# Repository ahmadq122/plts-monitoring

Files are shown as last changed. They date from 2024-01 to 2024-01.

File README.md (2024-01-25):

# PLTS Monitoring
A monitoring device for solar power plants
This device can read data from the solar panel system, measure current and voltage, and store data using microSD card media. 
In addition, the device has a user interface to display the measured data using an LCD 20x04.

## The block diagram of the solar power system monitoring system, including sensors, microcontroller, and user interface is as follows:
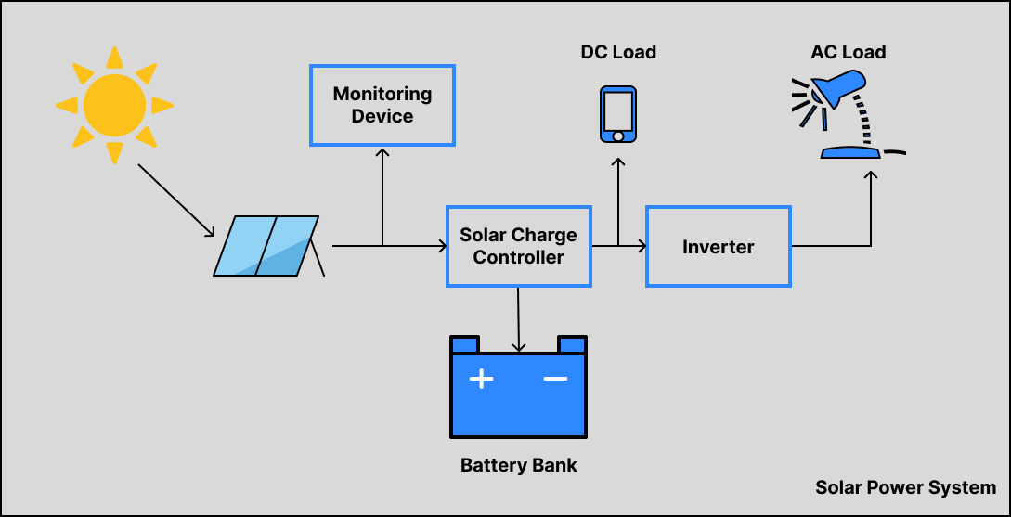
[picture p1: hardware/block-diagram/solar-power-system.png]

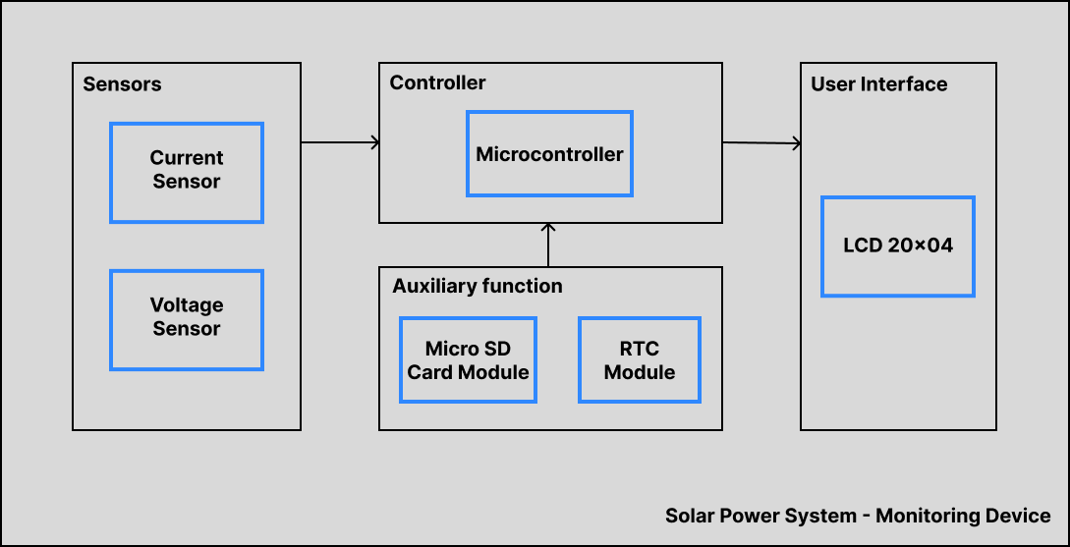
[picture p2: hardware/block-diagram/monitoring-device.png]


## Description of how the device works in general:
This tool will measure the voltage value generated by a solar panel and the DC electric current that is being flowed.
The measurement results will then be recorded in a certain time interval into a file document in a Micro SD card.

## The type of sensor that will be used to measure the current and voltage of the solar panel:
Current Sensor: ACS712
Voltage Sensor: ACPL-C87B

## Reasons for selecting the sensor:
ACS712
- Output voltage proportional to AC or DC currents
- Low-noise analog signal path
- Commonly used sensor and small output error 1.5% at Ambient temp 25C
- 
ACPL-C87B
- Isolated DC-bus voltage sensing
- High accuracy
- 0.1% non-linearity max
- 

## Schematic and PCB design using EDA application (Kicad):
- Please check kicad folder

## Create source code for the microcontroller (AVR ATmega 328p)
- Please check firmware folder

## Simulate the device design using the Proteus application:
- Please check proteus folder

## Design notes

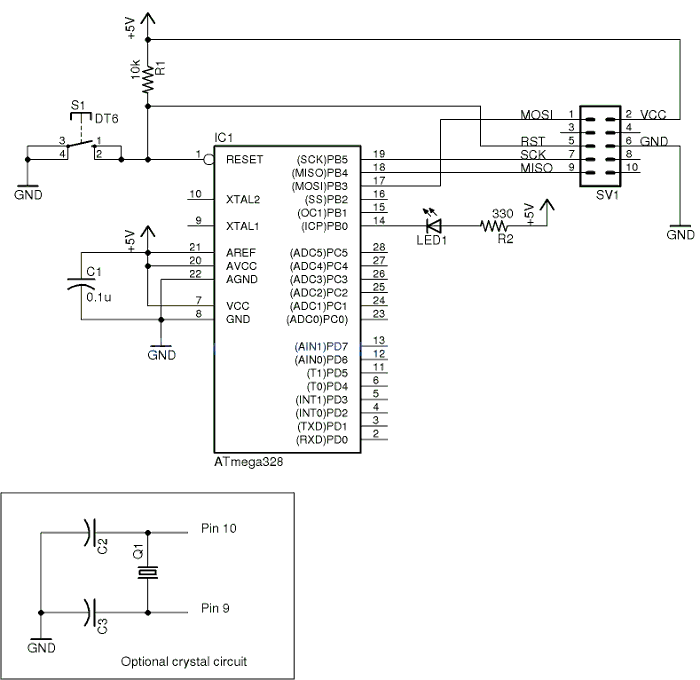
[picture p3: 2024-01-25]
hardware/controller/Minimum system.gif

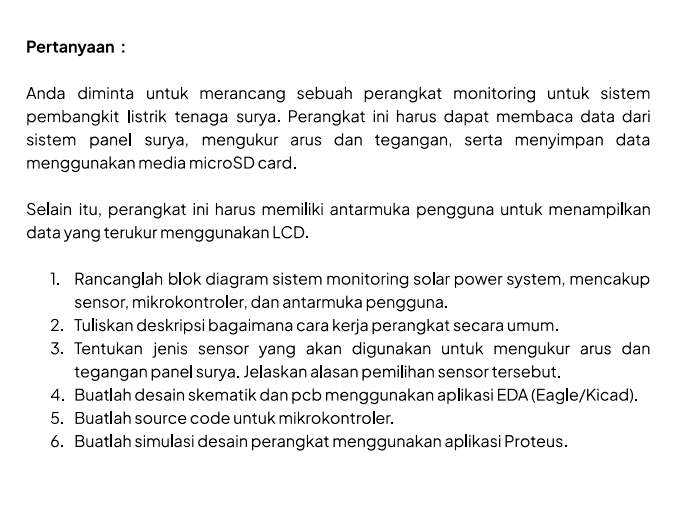
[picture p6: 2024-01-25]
task/task.png

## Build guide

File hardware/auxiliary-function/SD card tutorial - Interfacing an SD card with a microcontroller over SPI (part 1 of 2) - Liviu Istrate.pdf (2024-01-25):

SD card tutorial - Interfacing an SD card with a microcontroller over SP... https://www.programming-electronics-diy.xyz/2022/07/sd-card-tutorial-...

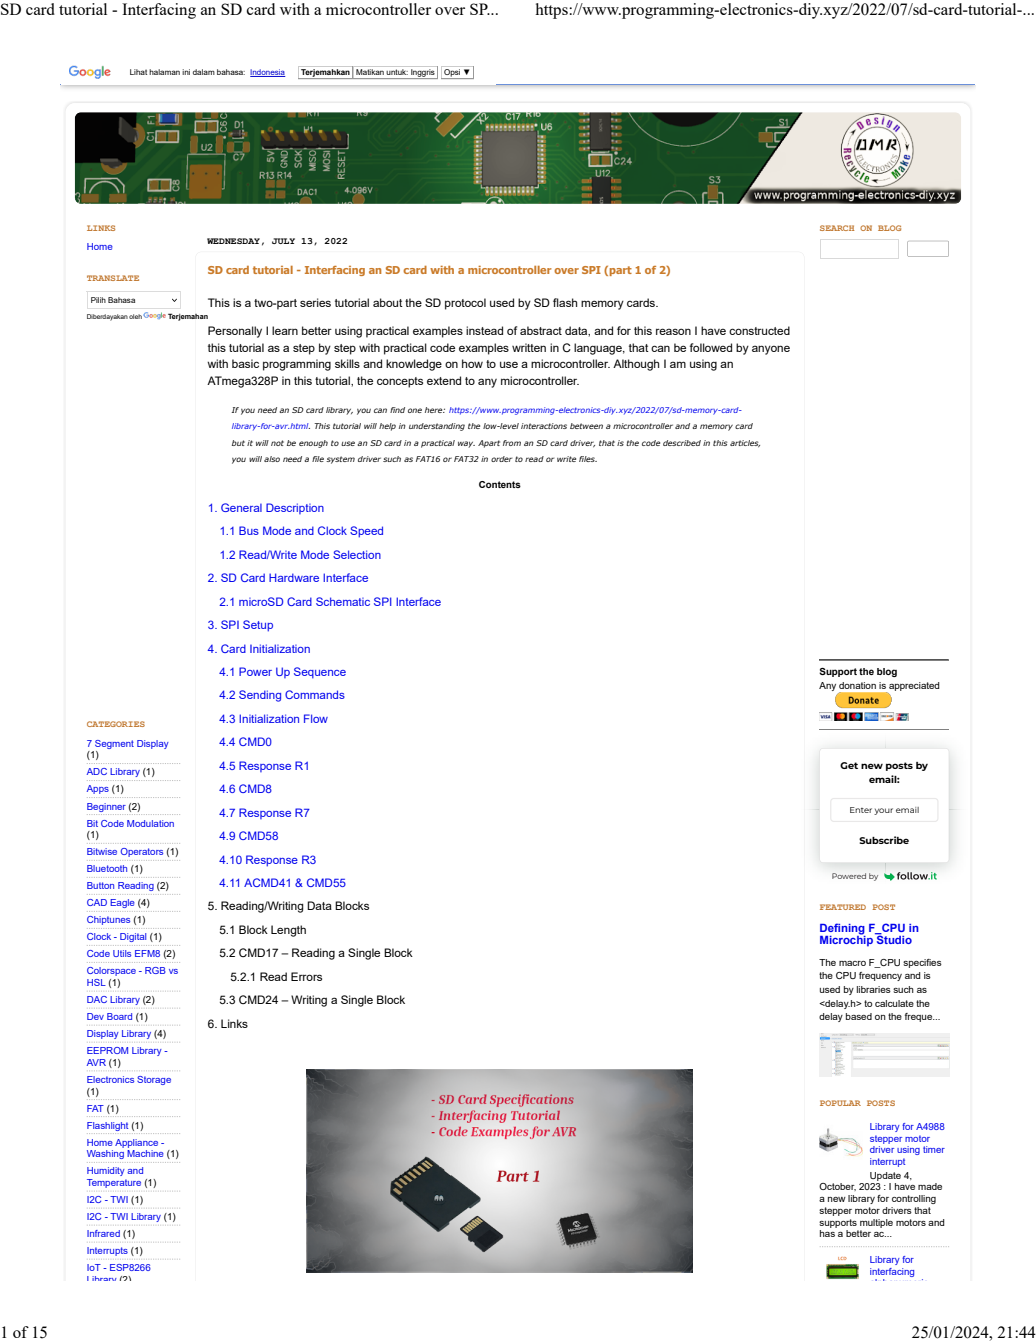
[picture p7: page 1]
WEDNESDAY, JULY 13, 2022; Contents; Home; LINKS; Pilih Bahasa; Diberdayakan oleh; Terjemahan; TRANSLATE; 7 Segment Display (1); ADC Library (1); Apps (1); Beginner (2); Bit Code Modulation (1); Bitwise Operators (1); Bluetooth (1); Button Reading (2); CAD Eagle (4); Chiptunes (1); Clock - Digital (1); Code Utils EFM8 (2); Colorspace - RGB vs HSL (1); DAC Library (2); Dev Board (1); Display Library (4); EEPROM Library - AVR (1); Electronics Storage (1); FAT (1); Flashlight (1)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

SEARCH ON BLOG

SD card tutorial - Interfacing an SD card with a microcontroller over SPI (part 1 of 2)

This is a two-part series tutorial about the SD protocol used by SD flash memory cards.

Personally I learn better using practical examples instead of abstract data, and for this reason I have constructed
this tutorial as a step by step with practical code examples written in C language, that can be followed by anyone
with basic programming skills and knowledge on how to use a microcontroller. Although I am using an
ATmega328P in this tutorial, the concepts extend to any microcontroller.

If you need an SD card library, you can find one here: https://www.programming-electronics-diy.xyz/2022/07/sd-memory-card-
library-for-avr.html. (https://www.programming-electronics-diy.xyz/2022/07/sd-memory-card-library-for-avr.html) This tutorial will help in understanding the low-level interactions between a microcontroller and a memory card
but it will not be enough to use an SD card in a practical way. Apart from an SD card driver, that is the code described in this articles,
you will also need a file system driver such as FAT16 or FAT32 in order to read or write files.

1. General Description (https://www.programming-electronics-diy.xyz/2022/07/sd-card-tutorial-interfacing-sd-card.html)
1.1 Bus Mode and Clock Speed (https://www.programming-electronics-diy.xyz/2022/07/sd-card-tutorial-interfacing-sd-card.html)
1.2 Read/Write Mode Selection (https://www.programming-electronics-diy.xyz/2022/07/sd-card-tutorial-interfacing-sd-card.html)
2. SD Card Hardware Interface (https://www.programming-electronics-diy.xyz/2022/07/sd-card-tutorial-interfacing-sd-card.html)
2.1 microSD Card Schematic SPI Interface (https://www.programming-electronics-diy.xyz/2022/07/sd-card-tutorial-interfacing-sd-card.html)
3. SPI Setup (https://www.programming-electronics-diy.xyz/2022/07/sd-card-tutorial-interfacing-sd-card.html)
4. Card Initialization (https://www.programming-electronics-diy.xyz/2022/07/sd-card-tutorial-interfacing-sd-card.html)
4.1 Power Up Sequence (https://www.programming-electronics-diy.xyz/2022/07/sd-card-tutorial-interfacing-sd-card.html)
4.2 Sending Commands (https://www.programming-electronics-diy.xyz/2022/07/sd-card-tutorial-interfacing-sd-card.html)
4.3 Initialization Flow (https://www.programming-electronics-diy.xyz/2022/07/sd-card-tutorial-interfacing-sd-card.html)
4.4 CMD0 (https://www.programming-electronics-diy.xyz/2022/07/sd-card-tutorial-interfacing-sd-card.html)
4.5 Response R1 (https://www.programming-electronics-diy.xyz/2022/07/sd-card-tutorial-interfacing-sd-card.html)
4.6 CMD8 (https://www.programming-electronics-diy.xyz/2022/07/sd-card-tutorial-interfacing-sd-card.html)
4.7 Response R7 (https://www.programming-electronics-diy.xyz/2022/07/sd-card-tutorial-interfacing-sd-card.html)
4.9 CMD58 (https://www.programming-electronics-diy.xyz/2022/07/sd-card-tutorial-interfacing-sd-card.html)
4.10 Response R3 (https://www.programming-electronics-diy.xyz/2022/07/sd-card-tutorial-interfacing-sd-card.html)
4.11 ACMD41 & CMD55 (https://www.programming-electronics-diy.xyz/2022/07/sd-card-tutorial-interfacing-sd-card.html)
5. Reading/Writing Data Blocks
5.1 Block Length
5.2 CMD17 – Reading a Single Block
5.2.1 Read Errors
5.3 CMD24 – Writing a Single Block
6. Links

Support the blog
Any donation is appreciated

Get new posts by
email:

Enter your email

The macro F_CPU specifies
the CPU frequency and is
used by libraries such as
<delay.h> to calculate the
delay based on the freque...

Library for A4988
stepper motor
driver using timer
interrupt (https://www.programming-electronics-diy.xyz/2017/10/library-for-a4988-stepper-motor-driver.html)
Update 4,

October, 2023 : I have made
a new library for controlling
stepper motor drivers that
supports multiple motors and
has a better ac...

Library (https://www.programming-electronics-diy.xyz/search/label/IoT%20-%20ESP8266%20Library) (2) | alphanumeric LCD modules with (https://www.programming-electronics-diy.xyz/2016/08/lcd-interfacing-library-4-and-8-bit-mode.html)

The Secure Digital (SD) Card was developed by the SD Association (SDA) (https://en.wikipedia.org/wiki/SD_Association) as an improvement over MMCs. The SD Card specifications were originally defined by MEI (Matsushita Electric Company), Toshiba Corporation and SanDisk Corporation. Currently, the specifications are controlled by the Secure Digital Association (SDA).

In addition to the mass storage specific flash memory chip, the SD Card includes an on-card intelligent controller which manages interface protocols, security algorithms for copyright protection, data storage and retrieval, as well as Error Correction Code (ECC) algorithms, defect handling and diagnostics, power management and clock control.

The data is transferred between the memory card and the host controller as data blocks in units of 512 bytes. The SD Card communication is based on an advanced nine-pin interface (Clock, Command, 4xData and 3xPower lines) designed to operate in a low voltage range. Both MMC/SD standards have their own proprietary protocols but they also support SPI which can be selected during card initialization. Since microcontrollers have SPI integrated hardware, this is the most used interface for memory cards.

SPI mode is a secondary mode of communication for SD cards – they power up in an "SD Bus protocol mode." To switch the card to SPI, the Chip Select line is driven low and CMD0 is sent.

The recommended file systems for memory cards are FAT12/16/32 or exFAT. Maximum volume sizes for each one are: 256MB, 4GB, 16TB* for FAT32 and 128PB for exFAT.

The MultiMediaCard and SD Card support multiple busses. Both cards support the 1-bit SPI bus that includes bus pins DATin, DATout, CLK, and CS.

The SD Card also supports a 4-bit and a 1-bit SD bi-directional bus mode. SD bus pins are CLK, CMD, and DATin 1-bit mode and CLK, CMD, and DAT[0:3] in 4-bit mode.

The MultiMediaCard also supports the 1-bit bi-directional MMC bus mode that has CLK, CMD, and DAT bus pins.

The CMD and DAT pins are bi-directional on the SD 1-bit, SD 4-bit, and MMC 1-bit.

The maximum burst rate achievable with the SD Card and MultiMediaCard depends on the clock speed and bus mode. The burst rate is the data transfer rate between the card’s buffer and host.

The write and read throughput rates of the SD Card and MultiMediaCard are slower than the burst rate because each card includes the busy time to write data from the card’s buffers to its internal Flash RAM, and busy time to read data from the internal Flash RAM to the card’s buffer. Since most designs use this write and read busy time to complete other processes, choosing a 1- or 4-bit bus mode can have a 4x speed effect on the time spent servicing the SD Card.

Another major MultiMediaCard and SD Card design consideration is the use of Singleblock or Multiblock command modes. Singleblock mode reads and writes data one block at a time; Multiblock mode reads and writes multiple blocks until a stop command is received.

Multiblock mode takes advantage of the multiple internal block buffers present in all MultiMediaCards or SD Cards. In Multiblock mode, when one block buffer gets full during write, the card gives the host access to the other empty block buffers to fill while programming the first block. The card does not enter a busy state until all block buffers are full.

In Singleblock mode, the card enters a busy state by forcing the DAT line low when the first block buffer is full and remains busy until the write process is complete. During the busy state, the host cannot send any additional data to the card because the card forces the DAT line low.

If speed is critical in a design, Multiblock mode is the faster and recommended mode. The more blocks that can be written in Multiblock mode the better the performance of the design. Therefore when planning the design, ensure that enough system RAM is designed in to support the multiblock capability. The performance gain will always outweigh the cost of the extra RAM. However, if speed is not critical – for example, a data-logger design that records only 512 bytes of data every minute – Singleblock mode is more than adequate.

### 1. GENERAL DESCRIPTION

### 1.1 BUS MODE AND CLOCK SPEED

Table 1: from "SanDisk Secure Digital Card v1.9"

### 1.2 READ/WRITE MODE SELECTION

LCD Driver IC (https://www.programming-electronics-diy.xyz/search/label/LCD%20Driver%20IC) (1)
LCD Library (https://www.programming-electronics-diy.xyz/search/label/LCD%20Library) (2)
LCD Library - EFM8 (https://www.programming-electronics-diy.xyz/search/label/LCD%20Library%20-%20EFM8)
(1)
LCD Library Alpha
Numeric Module (https://www.programming-electronics-diy.xyz/search/label/LCD%20Library%20Alpha%20Numeric%20Module) (1)
LED Controller (https://www.programming-electronics-diy.xyz/search/label/LED%20Controller) (3)
Logic Analyzer (https://www.programming-electronics-diy.xyz/search/label/Logic%20Analyzer) (1)
Mains Protection (https://www.programming-electronics-diy.xyz/search/label/Mains%20Protection) (1)
Memory Card (https://www.programming-electronics-diy.xyz/search/label/Memory%20Card) (3)
Microcontroller AVR (https://www.programming-electronics-diy.xyz/search/label/Microcontroller%20AVR)
(31)
Microcontroller EFM8 (https://www.programming-electronics-diy.xyz/search/label/Microcontroller%20EFM8)
(4)
Microcontroller
EFM8BB1 (https://www.programming-electronics-diy.xyz/search/label/Microcontroller%20EFM8BB1) (6)
Microcontroller
EFM8BB3 (https://www.programming-electronics-diy.xyz/search/label/Microcontroller%20EFM8BB3) (3)
PCB Homemade (https://www.programming-electronics-diy.xyz/search/label/PCB%20Homemade) (3)
Piezo Buzzer Library (https://www.programming-electronics-diy.xyz/search/label/Piezo%20Buzzer%20Library)
(1)
Pin Interrupt Library (https://www.programming-electronics-diy.xyz/search/label/Pin%20Interrupt%20Library)
(1)
Plot CSV (https://www.programming-electronics-diy.xyz/search/label/Plot%20CSV) (1)
POV Display (https://www.programming-electronics-diy.xyz/search/label/POV%20Display) (2)
Power Supply -
Capacitive (https://www.programming-electronics-diy.xyz/search/label/Power%20Supply%20-%20Capacitive) (1)
Programming AVR (https://www.programming-electronics-diy.xyz/search/label/Programming%20AVR)
(6)
PWM - Software (https://www.programming-electronics-diy.xyz/search/label/PWM%20-%20Software) (1)
Remote Control (https://www.programming-electronics-diy.xyz/search/label/Remote%20Control) (1)
RGB Library (https://www.programming-electronics-diy.xyz/search/label/RGB%20Library) (1)
Salvage Electronics (https://www.programming-electronics-diy.xyz/search/label/Salvage%20Electronics)
(1)
SD Card (https://www.programming-electronics-diy.xyz/search/label/SD%20Card) (3)
Sensor - PIR (https://www.programming-electronics-diy.xyz/search/label/Sensor%20-%20PIR) (2)
Sensor Library (https://www.programming-electronics-diy.xyz/search/label/Sensor%20Library) (2)
Stepper Motor
Drivers (https://www.programming-electronics-diy.xyz/search/label/Stepper%20Motor%20Drivers) (2)
Stepper Motor
Library (https://www.programming-electronics-diy.xyz/search/label/Stepper%20Motor%20Library) (3)
Temperature Sensor (https://www.programming-electronics-diy.xyz/search/label/Temperature%20Sensor)
(1)
Timing Library (https://www.programming-electronics-diy.xyz/search/label/Timing%20Library) (1)
UART Library (https://www.programming-electronics-diy.xyz/search/label/UART%20Library) (2)
USB to UART (https://www.programming-electronics-diy.xyz/search/label/USB%20to%20UART) (1)
UV Exposure Box (https://www.programming-electronics-diy.xyz/search/label/UV%20Exposure%20Box) (1)
VFD Display (https://www.programming-electronics-diy.xyz/search/label/VFD%20Display) (2)
Watchdog Library (https://www.programming-electronics-diy.xyz/search/label/Watchdog%20Library) (1)
Wireless Energy (https://www.programming-electronics-diy.xyz/search/label/Wireless%20Energy) (1)
Zener and LED
Tester (https://www.programming-electronics-diy.xyz/search/label/Zener%20and%20LED%20Tester) (1)

Name

Email *

Message *

Send

CONTACT

SUBSCRIBE TO

Posts

Comments

AVR microcontrollers (https://www.programming-electronics-diy.xyz/2016/08/lcd-interfacing-library-4-and-8-bit-mode.html)
This library provides an
interface between the
microcontroller and LCD
module. Note that this code is not for I2C modules. Main
features: ...

Playing music and
tones using a
piezo buzzer -
library for AVR
microcontrollers
using timer interrupt |
ATmega328 (https://www.programming-electronics-diy.xyz/2021/02/playing-music-and-tones-using-piezo.html)
This is a library for playing monophonic music using
PWM and a piezoelectric
buzzer. Monophonic means it can play only one note at a time...

How an outdoor
motion PIR
sensor switch
works with
schematic (https://www.programming-electronics-diy.xyz/2020/10/repair-of-outdoor-pir-d203s-thermal.html)
In this article I will be
explaining how a pyroelectric (PIR) sensor works and show the reverse engineered
schematic simulated in
LTspice...

AVR EEPROM
Library |
ATmega328P (https://www.programming-electronics-diy.xyz/2018/07/avr-eeprom-library.html)
Sometimes some
data needs to be
saved after the
microcontroller is powered off. Say you have a rotary encoder to set audio volume. When the ...
- 2024 (https://www.programming-electronics-diy.xyz/2024/) (2)
- 2023 (https://www.programming-electronics-diy.xyz/2023/) (6)
▼ 2022 (https://www.programming-electronics-diy.xyz/2022/) (9)
- August (https://www.programming-electronics-diy.xyz/2022/08/) (3)
▼ July (https://www.programming-electronics-diy.xyz/2022/07/) (4)
Library for MCP4725
DAC for AVR
microcontrollers (https://www.programming-electronics-diy.xyz/2022/07/library-for-mcp4725-dac-for-avr.html)
SD card tutorial -
Interfacing an SD
card with a m... (https://www.programming-electronics-diy.xyz/2022/07/sd-card-tutorial-interfacing-sd-card_13.html)
SD card tutorial -
Interfacing an SD
card with a m... (https://www.programming-electronics-diy.xyz/2022/07/sd-card-tutorial-interfacing-sd-card.html)
SD Memory Card
Library for AVR
Microcontrollers - ... (https://www.programming-electronics-diy.xyz/2022/07/sd-memory-card-library-for-avr.html)
- May (https://www.programming-electronics-diy.xyz/2022/05/) (1)
- February (https://www.programming-electronics-diy.xyz/2022/02/) (1)
- 2021 (https://www.programming-electronics-diy.xyz/2021/) (16)
- 2020 (https://www.programming-electronics-diy.xyz/2020/) (8)
- 2019 (https://www.programming-electronics-diy.xyz/2019/) (3)
- 2018 (https://www.programming-electronics-diy.xyz/2018/) (16)
- 2017 (https://www.programming-electronics-diy.xyz/2017/) (8)
- 2016 (https://www.programming-electronics-diy.xyz/2016/) (2)

BLOG ARCHIVE that records only 512 bytes of data every minute – Singleblock mode is more than adequate.

SDC | miniSD | - SD
- SPI
PIN | SD | SPI | SD | SPI | Description
1 | DAT3 | CS | DAT3 | CS | - SD Serial Data 3
- SPI Card Select (active Low)
2 | CMD | DI | CMD | DI | - Command, response
- SPI Serial Data In (MOSI)
3 | VSS | VSS | Ground
4 | VDD | VDD | Power. Usually 2.7 to 3.6V and minimum 100mA. Not 5V tolerant!
5 | CLK | CLK | Serial Clock
6 | VSS | VSS | Ground
7 | DAT0 | DO | DAT0 | DO | - SD Serial Data 0 - SPI Serial Data Out (MISO)
8 | DAT1 | NC | DAT1 | NC | - SD Serial Data 1 - Unused
9 | DAT2 | NC | DAT2 | NC | - SD Serial Data 2 - Unused
10 | | | NC | | Not Connected
11 | | | NC | | Not Connected
microSD | - SD
- SPI
PIN | SD | SPI | Description
1 | DAT2 | NC | - SD Serial Data 2
- Unused
2 | DAT3 | CS | - SD Serial Data 3
- SPI Card Select (active Low)
3 | CMD | DI | - Command, response
- SPI Serial Data In (MOSI)
4 | VDD | Power. Usually 2.7 to 3.6V and minimum 100mA. Not 5V tolerant!
5 | CLK | Serial Clock
6 | VSS | Ground
7 | DAT0 | DO | - SD Serial Data 0 - SPI Serial Data Out (MISO)
8 | DAT1 | NC | - SD Serial Data 1 - Unused

Reading and writing to an SD Card and MultiMediaCard is generally done in 512 byte blocks, however, erasing often occurs in much larger blocks. The NAND architecture used by SanDisk and other card vendors currently has Erase Block sizes of (32) or (64) 512 byte blocks, depending on card capacity. In order to re-write a single 512 byte block, all other blocks belonging to the same Erase Block will be simultaneously erased and need to be rewritten.

### 2. SD CARD HARDWARE INTERFACE

### 2.1 MICROSD CARD SCHEMATIC SPI INTERFACE

The microcontroller and the memory card must use the same voltage. If the microcontroller is powered from 5V and the card is on 3.3V there needs to be a logic voltage level shifter such as 74AHC125D.

According to the SD card specification, unused Data lines on the card must be terminated with pull-up resistors. Floating pins can lead to excessive power consumption.

A pull-up on the DO line is needed because, until initialized into SPI mode, the DO pin is open drain.

A pull-up on the CS (Card Select) is recommended because it could take many milliseconds until the microcontroller enables the CS pin High and during that time the SPI pins could have random values and possibly corrupting the card.

Some sockets have a 9th pin that optionally can be pulled high using a microcontroller pin set as an input high. This is a mechanical switch. When the card is inserted the pin goes Low allowing the microcontroller to detect card insertion/removal.

To be able to access the SD card we first need to set up the SPI on the microcontroller. The SPI clock (CLK) idles low and the output is sampled on the leading edge, which corresponds to CPOL = 0 and CPHA = 0. Since this is the default mode on our micro, we don’t have to change the mode in SPCR (SPI Control Register). Although modern SD Cards can operate at very high speeds it is recommended to set SCK to a frequency between 100kHz and 400kHz during the initialization process and then change it to maximum speed.

It is a good practice to abstract the pins used by using defines. This way it will be easier to change the pins later on.

// SPI0 I/O pins (MOSI and SCK)
#define SPI0_PORT | PORTB // SPI PORT

#define SPI0_DDR | DDRB // SPI DDR

#define SPI0_PINS | PINB // State of each pin on SPI port

#define SPI0_MOSI_PIN | PB3 | // SDA pin

#define SPI0_SCK_PIN | PB5 | // SCK pin

// SPI Chip Select pin
#define CARD_CS_DDR | DDRB

#define CARD_CS_PORT | PORTB

#define CARD_CS_PIN | PB2

The CS (Card Select or Chip Select) is the SPI SS0 pin and is set to PB2 but can be changed to any other port and pin. Regardless of what CS pin you choose to use it is important that the SS SPI pin be set as an output high or low otherwise the SPI won't work properly.

All SPI commands to the SD card require the microcontroller to first assert the Chip Select line, which means pulling it low. When we are done, we will need to return the Chip Select to a high state. Some pre-processor macros suits this purpose very well.

#define SPI_CARD_CS_DISABLE() | CARD_CS_PORT |= (1 << CARD_CS_PIN)

#define SPI_CARD_CS_ENABLE() | CARD_CS_PORT &= ~(1 << CARD_CS_PIN)

Now that we defined our pins let’s create a function for SPI initialization. Making the function static will decrease the code size.

### 3. SPI SETUP

/*______________________________________________ SPI – Initialization
________________________________________________*/
static void SPI_Init(void){
// Set MOSI and SCK as output
SPI0_DDR |= (1 << SPI0_MOSI_PIN) | (1 << SPI0_SCK_PIN);
CARD_CS_DDR |= (1 << CARD_CS_PIN); // CS pin

// Enable SPI, Master mode
SPCR0 = (1 << SPE0) | (1 << MSTR0);

// Start with a lower speed for older cards (100-400kHz) SPSR0 = (1 << 0);
SPCR0 |= (1 << SPR01); // set clock rate fosc/32
}

This function sets CS, MOSI and SCK pins as output, the SPI is enabled in Master mode and the SPI clock prescaler is set to 32 for a lower frequency.

Next function is used to receive one byte from the SPI. Because the memory card needs a clock pulse to send the bytes, we need to put some dummy data on the transmit line.

/*_________________________________________________
SPI – Receive and returns one byte only ___________________________________________________*/
static uint8_t SPI_ReceiveByte(void){
// Write dummy byte out to generate clock, then read data from MISO SPDR0 = 0xFF;

// Wait until the Busy bit is cleared
while(!(SPSR0 & (1 << SPIF0)));

return SPDR0;
}

To send a byte is even simpler:

/*__________________________________________________ SPI - Send a byte
____________________________________________________*/ static void SPI_SendByte(uint8_t byte){
SPDR0 = byte;

// Wait until the Busy bit is cleared while(!(SPSR0 & (1 << SPIF0)));
}

Now that the SPI is ready we can proceed with card initialization.

The power up sequence from the physical spec is shown below.

Looking at the above diagram we see that it needs at least 1 msec delay and 74 clock cycles before sending commands to the SD Card. Since we get 8 clock cycles with each byte, we can send 10 bytes for a total of 80 clock cycles. In the notes of this section, the spec also specifies that CS must be held high during this period.

Before making a function to initialize the SD card we need to define some return codes to see if the function succeeded and if not what was the cause.

### 4. CARD INITIALIZATION 4.1 POWER UP SEQUENCE

succeeded and if not what was the cause.

/* Card initialization return codes (SD_RETURN_CODES) */ typedef enum {
SD_OK,
SD_IDLE_STATE_TIMEOUT,
SD_GENERAL_ERROR,
SD_CHECK_PATTERN_MISMATCH, SD_NONCOMPATIBLE_VOLTAGE_RANGE, SD_POWER_UP_BIT_NOT_SET,
SD_NOT_SD_CARD
} SD_RETURN_CODES;

SD_RETURN_CODES sd_init(void){
uint8_t SD_Response[5]; // array to hold response uint8_t cmdAttempts = 0;

// SPI Setup
SPI_Init();

// Give SD card time to power up _delay_ms(1);

// Send 80 clock cycles to synchronize
// The card must be deselected during this time sd_deassert_cs();
for(uint8_t i = 0; i < 10; i++) SPI_SendByte(0xFF);

return SD_OK;
}

We will be adding more code to this function as we go along. You might have noticed a new function and actually we will need to like this: assert() and deassert().

/*_________________________________________________________
Assert Chip Select Line by sending a byte
before and after changing the CS line ___________________________________________________________*/ static void sd_assert_cs(void){
SPI_SendByte(0xFF);
SPI_CARD_CS_ENABLE();
SPI_SendByte(0xFF);
}

/*__________________________________________________________ De-Assert Chip Select Line by sending a byte
before and after changing the CS line ____________________________________________________________*/ static void sd_deassert_cs(void){
SPI_SendByte(0xFF);
SPI_CARD_CS_DISABLE();
SPI_SendByte(0xFF);
}

Both functions provide 8 clocks before and after changing the state of CS pin. This is recommended to ensure the card recognizes the change in CS. These extra bytes are not always necessary but many people have had issues when multiple cards are on the bus.

SD card commands are 6 bytes long (48 bits) and contain a command index, arguments, and CRC. The command index field is used to tell the SD card which command you are sending. For example, if CMD1 is required, then the 6 bits in command index should be set to 000001b. The argument field is used in some commands and is ignored by other. Whenever no arguments are needed, we will fill this field with zeros. The

### 4.2 SENDING COMMANDS

commands and is ignored by other. Whenever no arguments are needed, we will fill this field with zeros. The Cyclic Redundancy Check (CRC) is used to ensure that the data has been correctly received by the SD card. In

SPI mode the CRC is optional with few exceptions but in those cases, the spec manual provides us with precalculated values. In the cases where the CRC is not needed, we will set it to zero.

To send commands to the SD card we need a new function that takes an 8-bit command index, a 32-bit argument, and an 8-bit CRC.

/*_________________________________________________________________ Send a command to the card

cmd | 8-bit command index
arg | a 32-bit argument
crc | an 8-bit CRC
__________________________________________________________________*/ static void sd_command(uint8_t cmd, uint32_t arg, uint8_t crc){
// Transmit command
SPI_SendByte(cmd | 0x40);

// Transmit argument
SPI_SendByte((uint8_t)(arg >> 24)); SPI_SendByte((uint8_t)(arg >> 16)); SPI_SendByte((uint8_t)(arg >> 8)); SPI_SendByte((uint8_t)(arg));

// Transmit CRC
SPI_SendByte(crc | 0x01);
}

Note in the command format table, that the command index is only 6 bits long. The 2 most significant bits of the command is always set to 01b. In order to set bit 47 to 1, we need to bitwise OR our input 'cmd' with 0×40.

The CRC is only 7 bits long, and the end bit of any command is always 1 so we bitwise OR the 'crc' argument with 0×01.

The SPI mode initialization flow for an SD card is shown in the diagram below. It might look complicated but is not really.

From Power-on stage there are two main branches that we need to implement not only to initialize the SD card in SPI mode but also to detect what type of card this is. The end results could be:

- Unusable Card: do to non-compatible voltage range, check patter error
- Not SD Memory Card: could be an MMC

### 4.3 INITIALIZATION FLOW

- Not SD Memory Card: could be an MMC
- Version 1.x cards: Standard Capacity SD Memory Card (SDSC)
- Version 2 or later: Standard Capacity SD Memory Card (SDSC)
- Version 2 or later: High Capacity (SDHC) or Extended Capacity (SDXC) Memory Card

The first step is to send CMD0. Below is the description of CMD0 from the physical spec.

This command is used to reset the memory card. The argument is 'stuff bits', which means it will be ignored by the SD card so we can send whatever, and the response is of type R1 (more on that later).

We specify CMD0 simply by setting 'command index' to 0 in our command, and since the argument can be whatever we will set it to 0×00000000. The CRC that corresponds to these bits are provided by the physical spec on page 43 as a 7-bit which is 10010100b. To pass this to our function, we need an 8-bit value. We can put a 0 (0×94) or a 1 at the end but it does not matter as our function will always set the final bit to 1.

/* Command List */
// CMD0 – GO_IDLE_STATE
#define CMD0 | 0

#define CMD0_ARG | 0×00000000

#define CMD0_CRC | 0×94

Before sending CMD0 we need to be able to read the response called R1.

The R1 format is shown below from the physical spec.

R1 is a single byte, where the MSB is always 0, and every other bit represents an error condition. Here is the function for reading the R1:

/*_______________________________________________________________________
Wait for a response from the card other than 0xFF which is
the normal state of the MISO line. Timeout occurs after 16 bytes.
return | response code
_________________________________________________________________________*/ static uint8_t sd_read_response1(void){
uint8_t i = 0, response = 0xFF;

// Keep polling until actual data received
while((response = SPI_ReceiveByte()) == 0xFF){ i++;
| // If no data received for 16 bytes, break if(i > 16) break;

}

return response;
}

The function waits for the MISO line to change it’s state. The idle state of the MISO line is high which means 0xFF. If after reading 16 bytes, the state doesn’t change then it exits with 0xFF response. The timeout is needed because it takes some time for the card to respond. It should take the SD card 8 clock cycles to respond but it doesn’t hurt to use 16 just for good measure.

Now the card initialization function looks like this:

SD_RETURN_CODES sd_init(void){
uint8_t SD_Response[5]; // array to hold response uint8_t cmdAttempts = 0;

// SPI Setup
SPI_Init();

### 4.4 CMD0

### 4.5 RESPONSE R1

SPI_Init();

// Give SD card time to power up _delay_ms(1);

// Send 80 clock cycles to synchronize
// The card must be deselected during this time sd_deassert_cs();
for(uint8_t i = 0; i < 10; i++) SPI_SendByte(0xFF);

// Send CMD0 (GO_IDLE_STATE) - R1 response
// Resets the SD Memory Card
// Argument is 0×00 for the reset command, pre-calculated checksum while(SD_Response[0] != 0x01){
// Assert chip select
sd_assert_cs();

// Send CMD0
sd_command(CMD0, CMD0_ARG, CMD0_CRC);

// Read R1 response
SD_Response[0] = sd_read_response1();

// Send some dummy clocks after GO_IDLE_STATE // Deassert chip select
sd_deassert_cs();

cmdAttempts++;

if(cmdAttempts > 10){
SPI_CARD_CS_DISABLE();
return SD_IDLE_STATE_TIMEOUT; }
}

return SD_OK;
}

Resetting the card could take some time therefore the CMD0 is transmitted up to 10 times or until the response is 0×01 which means idle state (bit 0 in R1 set to 1). After the timeout the chip is deselected and the function

returns SD_IDLE_STATE_TIMEOUT.

Next command in the initialization flow is CMD8, SEND_IF_COND (send interface condition), R7 response.

One use of this command is to check whether the card is first generation or version 2.00 (or later). If the card is of first generation, it will respond with R1 with bit 2 set (illegal command). This necessitates going down the left path in the initialization diagram. If the card does not indicate an illegal command we will go through the Version 2.00 path. I couldn’t find a version 1.x card to test but some code will be provided regardless.

Another use is to send the host supply voltage information and asks the accessed card whether it can operate in supplied voltage range. Reserved bits shall be set to '0'.

In the above table the command argument (bits 39:8) is expanded and shows what should be. Reserved bits must be 0. Voltage supplied (VHS) will be set to 0001b since the 3.3V supply voltage is the most common. The check pattern is an arbitrary string of bits that can be set to any value, which the SD card will return in the response to ensure the command was processed correctly. Per page 40 of the version 2.00 physical spec, the recommended pattern is ‘10101010b’. CMD8 is the only command other than CMD0 that requires a correct CRC. Using the recommended check pattern and 3.3V the correct CRC is 1000011b. Command 8 is defined in hexadecimal values as:

// CMD8 – SEND_IF_COND (Send Interface Condition)
#define CMD8 | 8

#define CMD8_ARG | 0×0000001AA

#define CMD8_CRC | 0×86 // (1000011 << 1)

### 4.6 CMD8

Command 8 introduced another type of response named R7 and the format can be seen below.

R7 is 5 bytes long, and the first byte is identical to R1. The "echo-back" is the check pattern we sent in the command and now it is returned back. First generation cards will only return R1 with the illegal bit command set. To read R7 let’s make another function.

/*________________________________________________________________
Read Response 3 or 7 which is 5 bytes long
res | Pointer to a 5 bytes array
__________________________________________________________________*/ static void sd_read_response3_7(uint8_t *res){
res[0] = sd_read_response1(); // read response 1 in R3 or R7

if(res[0] > 1) return; // if error reading R1, return

res[1] = SPI_ReceiveByte();
res[2] = SPI_ReceiveByte();
res[3] = SPI_ReceiveByte();
res[4] = SPI_ReceiveByte();
}

Skipping a bit ahead I have named the function to indicate it can read Response 3 and R7 as well since they are the same. Now we can see why SD_Response[5] in the initialization function is 5 bytes long. If the card is of first generation or an error occurs it will return only R1 so if res[0] does not equal 0×01 or 0×00 then we return.

Now CMD8 can be added to our initialization function.

sd_assert_cs();
sd_command(CMD8, CMD8_ARG, CMD8_CRC); sd_read_response3_7(SD_Response); sd_deassert_cs();

// Enable maximum SPI speed
SPCR0 &= ~(1 << SPR01); // set clock rate fosc/2

// Select initialization sequence path
if(SD_Response[0] == 0x01){
| // The card is Version 2.00 (or later) or SD memory card // Check voltage range if(SD_Response[3] != 0x01){ return SD_NONCOMPATIBLE_VOLTAGE_RANGE;

}

| // Check echo pattern if(SD_Response[4] != 0xAA){ return SD_CHECK_PATTERN_MISMATCH;

}

}else if(SD_Response[0] == 0x05){
| // Response code 0×05 = Idle State + Illegal Command indicates // the card is of first generation. SD or MMC card.

}else{
| return SD_GENERAL_ERROR;
}

The initialization sequence path is selected based on the R7 response. Also the SPI speed is set to maximum by setting the prescaler to 2 instead of 32 as in the SPI init function. Ideally you would query the card for maximum speed capability by sending the appropriate command but that takes extra code and space on the MCU. If the card is version 2 or greater, the supported voltage range and echo pattern returned by the card are checked if they equal with the ones transmitted by us.

Moving to the next step, CMD58 – reads OCR (operation conditions register). The response to this command is R3. Here the CRC does not matter unless the CRC option is activated using the appropriate command.

### 4.7 RESPONSE R7

### 4.9 CMD58

// CMD58 – read OCR (Operation Conditions Register)
#define CMD58 | 58

#define CMD58_ARG | 0×00000000

#define CMD58_CRC | 0×00

The response format R3 is shown below.

Just like with response 7, first byte is the same as R1 and the following 4 bytes are the contents of OCR, which is defined as below.

Bits 15-24 indicates the voltage ranges supported by this card. Since all cards should support 3.3V, there is no need to check it here. This fields are important only if you need to use the 1.8V supply voltage in which case the bit 24 should be checked but that would be valid only if the card is of UHS type and that can be determined by checking the bit 29.

Bit 31 is the card power up status, which is low if the card has not finished the power up routine. And bit 30, the card capacity status, which is only valid if the power up status is set (bit 31). Bit 30 indicates that the card is a high capacity SD card (SDHC) or extended capacity SD card (SCXC) and not a standard capacity SD card (SDSC).

At this stage this command can only be used to check the supported voltage ranges since the bit 31 will only be set after the next command (ACMD41) and after this command CMD58 will be used again like it is shown in the initialization chart. The response is not used here but it must be read in order for the clock to be generated and the card to clear the response flags.

We already have a function that can read response R3 so the next code is added to the init function:

// CMD58 – read OCR (Operation Conditions Register) - R3 response
// Reads the OCR register of a card
sd_assert_cs();
sd_command(CMD58, CMD58_ARG, CMD58_CRC); sd_read_response3_7(SD_Response); sd_deassert_cs();

ACMD41 – SD_SEND_OP_COND (send operating condition) is used to start the card's initialization process and is the next command in the initialization flow diagram. The ‘A’ before the command name signifies that it is an application specific command. Before this type of commands we need to inform the card controller that this is an application specific command rather than a standard command by first sending CMD55 – APP_CMD.

### 4.10 RESPONSE R3

### 4.11 ACMD41 & CMD55

ACMD41 has the same format as CMD41. If CMD55 is not sent first, then sending a command with 41 in the first byte will be interpreted as CMD41, which is a reserved command and will result in an error response.

All we can set in ACMD41 argument is bit 30 (HCS) which indicates that we support high capacity cards and set reserved bits to ‘0’.

// CMD55 – APP_CMD
#define CMD55 | 55

#define CMD55_ARG | 0×00000000

#define CMD55_CRC | 0×00

// ACMD41 – SD_SEND_OP_COND (Send Operating Condition)
// ACMD stands for Application Specific Command and before issued, // the CMD55 must be sent first
#define ACMD41 | 41

#define ACMD41_ARG | 0×40000000

#define ACMD41_CRC | 0×00

In the power-up diagram it is shown that the initialization process can take up to 1 second so we need another function that sends CMD55 followed by ACMD41 until the card returns ‘in_idle_state’ = 0 or the timeout condition occurs. The loop is set to run up to 100 times and each loop has a 10ms delay resulting in a 1000ms timeout.

static uint8_t SD_CardType;

/*____________________________________________________________
Send ACMD41 – Sends host capacity support information and activates the card's initialization process. Reserved bits shall be set to '0'. ______________________________________________________________*/ static SD_RETURN_CODES sd_command_ACMD41(void){
uint8_t response;
uint8_t i = 100;

// Initialization process can take up to 1 second so we add a 10ms delay // and a maximum of 100 iterations

do{
// CMD55 – APP_CMD – R1 response
sd_assert_cs();
sd_command(CMD55, CMD55_ARG, CMD55_CRC);
sd_read_response1();
sd_deassert_cs();

// ACMD41 – SD_SEND_OP_COND (Send Operating Condition) - R1 response sd_assert_cs();

if(SD_CardType == SD_V1_SDSC)
| sd_command(ACMD41, 0, ACMD41_CRC);
else
| sd_command(ACMD41, ACMD41_ARG, ACMD41_CRC);

response = sd_read_response1();
sd_deassert_cs();

i--;
_delay_ms(10);

}while((response != 0) && (i > 0));

// Timeout
if(i == 0) return SD_IDLE_STATE_TIMEOUT;

return response;
}

The variable SD_CardType holds the card type and the values can be:

// Card Type
#define SD_V1_SDSC | 1

#define SD_V2_SDSC | 2

#define SD_V2_SDHC_SDXC | 3

If the card is SDSC version 1 then bit 30 (HCS) must be 0 and SD_CardType | is used for that. In the initialization

SD_CardType
function we use this new function like this:

if(sd_command_ACMD41() > 0) return SD_IDLE_STATE_TIMEOUT;

That means if the function doesn’t return 0 it waited for 1 second and the card was still in idle mode or an error occurred. The response R1 could be checked to see which bit is set by using bit-wise AND like this:

// R1 Response
#define PARAM_ERROR(X) | X & 0b01000000

#define ADDR_ERROR(X) | X & 0b00100000

#define ERASE_SEQ_ERROR(X) | X & 0b00010000

#define CRC_ERROR(X) | X & 0b00001000

#define ILLEGAL_CMD(X) | X & 0b00000100

#define ERASE_RESET(X) | X & 0b00000010

#define IN_IDLE(X) | X & 0b00000001

The last thing to do is send CMD58 again and check power up status bit (OCR bit 31) and Card Capacity Status (bit 30) that indicates if this is an SDSC or SDHC, SDXC card.

// CMD58 – read OCR (Operation Conditions Register) - R3 response
sd_assert_cs();
sd_command(CMD58, CMD58_ARG, CMD58_CRC); sd_read_response3_7(SD_Response);
sd_deassert_cs();

// Check if the card is ready
// Read bit OCR 31 in R3
if(!(SD_Response[1] & 0x80)){
return SD_POWER_UP_BIT_NOT_SET; }

// Read CCS bit OCR 30 in R3 if(SD_Response[1] & 0x40){
// SDXC or SDHC card
SD_CardType = SD_V2_SDHC_SDXC; }else{
// SDSC
SD_CardType = SD_V2_SDSC;
}

Now the complete initialization function looks like this:

SD_RETURN_CODES sd_init(void){
uint8_t SD_Response[5]; // array to hold response uint8_t cmdAttempts = 0;

// SPI Setup
SPI_Init();

// Give SD card time to power up _delay_ms(1);

// Send 80 clock cycles to synchronize
// The card must be deselected during this time sd_deassert_cs();
for(uint8_t i = 0; i < 10; i++) SPI_SendByte(0xFF);

// Send CMD0 (GO_IDLE_STATE) - R1 response
// Resets the SD Memory Card
// Argument is 0×00 for the reset command, precalculated checksum while(SD_Response[0] != 0x01){
// Assert chip select
sd_assert_cs();

// Send CMD0
sd_command(CMD0, CMD0_ARG, CMD0_CRC);

// Read R1 response
SD_Response[0] = sd_read_response1();

// Deassert chip select
sd_deassert_cs();

cmdAttempts++;

if(cmdAttempts > 10){
SPI_CARD_CS_DISABLE();
return SD_IDLE_STATE_TIMEOUT; }
}

// Send CMD8 - SEND_IF_COND (Send Interface Condition) - R7 response (or R1 for < V2 cards)

// Sends SD Memory Card interface condition that includes host supply voltage information and asks t // accessed card whether card can operate in supplied voltage range.
// Check whether the card is first generation or Version 2.00 (or later).
// If the card is of first generation, it will respond with R1 with bit 2 set (illegal command)
// otherwise the response will be 5 bytes long R7 type
// Voltage Supplied (VHS) argument is set to 3.3V (0b0001)
// Check Pattern argument is the recommended pattern '0b10101010'
// CRC is 0b1000011 and is precalculated
sd_assert_cs();
sd_command(CMD8, CMD8_ARG, CMD8_CRC); sd_read_response3_7(SD_Response); sd_deassert_cs();

// Enable maximum SPI speed
SPCR0 &= ~(1 << SPR01); // set clock rate fosc/2

// Select initialization sequence path
if(SD_Response[0] == 0x01){
// The card is Version 2.00 (or later) or SD memory card // Check voltage range
if(SD_Response[3] != 0x01){
return SD_NONCOMPATIBLE_VOLTAGE_RANGE;
}

// Check echo pattern
if(SD_Response[4] != 0xAA){
return SD_CHECK_PATTERN_MISMATCH;
}

// CMD58 – read OCR (Operation Conditions Register) - R3 response sd_assert_cs();
sd_command(CMD58, CMD58_ARG, CMD58_CRC); sd_read_response3_7(SD_Response);
sd_deassert_cs();

// ACMD41 – starts the initialization process – R1 response
// Continue to send ACMD41 (always preceded by CMD55) until the card responds // with 'in_idle_state', which is R1 = 0×00.
if(sd_command_ACMD41() > 0) return SD_IDLE_STATE_TIMEOUT;

// CMD58 – read OCR (Operation Conditions Register) - R3 response sd_assert_cs();
sd_command(CMD58, CMD58_ARG, CMD58_CRC); sd_read_response3_7(SD_Response);
sd_deassert_cs();

// Check if the card is ready
// Read bit OCR 31 in R3
if(!(SD_Response[1] & 0x80)){
return SD_POWER_UP_BIT_NOT_SET; }

// Read CCS bit OCR 30 in R3 if(SD_Response[1] & 0x40){
// SDXC or SDHC card
SD_CardType = SD_V2_SDHC_SDXC; }else{
// SDSC
SD_CardType = SD_V2_SDSC;
}

}else if(SD_Response[0] == 0x05){
// Response code 0×05 = Idle State + Illegal Command indicates // the card is of first generation. SD or MMC card. SD_CardType = SD_V1_SDSC;

// ACMD41
SD_Response[0] = sd_command_ACMD41(); if(ILLEGAL_CMD(SD_Response[0])) return SD_NOT_SD_CARD; if(SD_Response[0]) return SD_IDLE_STATE_TIMEOUT;

}else{
return SD_GENERAL_ERROR;
}

// Read and write operations are performed on SD cards in blocks of set lengths.
// Block length can be set in Standard Capacity SD cards using CMD16 (SET_BLOCKLEN). // For SDHC and SDXC cards the block length is always set to 512 bytes.

return SD_OK;
}

}

Newer Post (https://www.programming-electronics-diy.xyz/2022/07/sd-card-tutorial-interfacing-sd-card_13.html) | Home (https://www.programming-electronics-diy.xyz/) | Older Post (https://www.programming-electronics-diy.xyz/2022/07/sd-memory-card-library-for-avr.html)

Share

Posted by Liviu Istrate (https://www.blogger.com/profile/15953813368190792312) at July 13, 2022 (https://www.programming-electronics-diy.xyz/2022/07/sd-card-tutorial-interfacing-sd-card.html) Labels: Memory Card, (https://www.programming-electronics-diy.xyz/search/label/Memory%20Card) SD Card (https://www.programming-electronics-diy.xyz/search/label/SD%20Card)

In the next part (https://www.programming-electronics-diy.xyz/2022/07/sd-card-tutorial-interfacing-sd-card_13.html) we will see how to read and write the SD card. Hopefully I will see you there.

You can also download this tutorial in a PDF format at the link below. If you find it useful, consider a small donation at the link provided.

SD card tutorial - Interfacing an SD card with a microcontroller over SPI, v1.0, 2022.pdf (https://drive.google.com/file/d/1JvYiGaktLKal2DwfZ1k_rzlh6gAH2MIV/view?usp=sharing)

Donations link: https://paypal.me/alientransducer

Replies

Reply

2 comments:

Prado 23 October, 2023 13:23 (https://www.programming-electronics-diy.xyz/2022/07/sd-card-tutorial-interfacing-sd-card.html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)
Hi Liviu, I have used the Nuvoton MS52fb9ae controller with sdcc and eclipse. I made changes in the code to suite the controller. Upon building the project, i get this error :

?ASlink-Warning-Undefined Global '___ulonglong2fs' referenced by module 'main'

I am not able to understand where i went wrong. Please can you help ?
Reply

Liviu Istrate (https://www.blogger.com/profile/15953813368190792312) 23 October, 2023 20:42 (https://www.programming-electronics-diy.xyz/2022/07/sd-card-tutorial-interfacing-sd-card.html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)
Hi. I am not familiar with that platform but from what I can tell, a global variable is not defined. Maybe it has to do with the order you include the files in the main.c? I don't know. There should be a line number in the error message that would indicate what part of the code is causing the problem.

Home (http://www.programming-electronics-diy.xyz/)
Privacy Policy (https://www.programming-electronics-diy.xyz/p/privacy-policy.html)

PAGES

Liviu Istrate @ 2017. Theme images by merrymoonmary. (http://www.istockphoto.com/googleimages.php?id=10871280&platform=blogger&langregion=en) Powered by Blogger. (https://www.blogger.com/)

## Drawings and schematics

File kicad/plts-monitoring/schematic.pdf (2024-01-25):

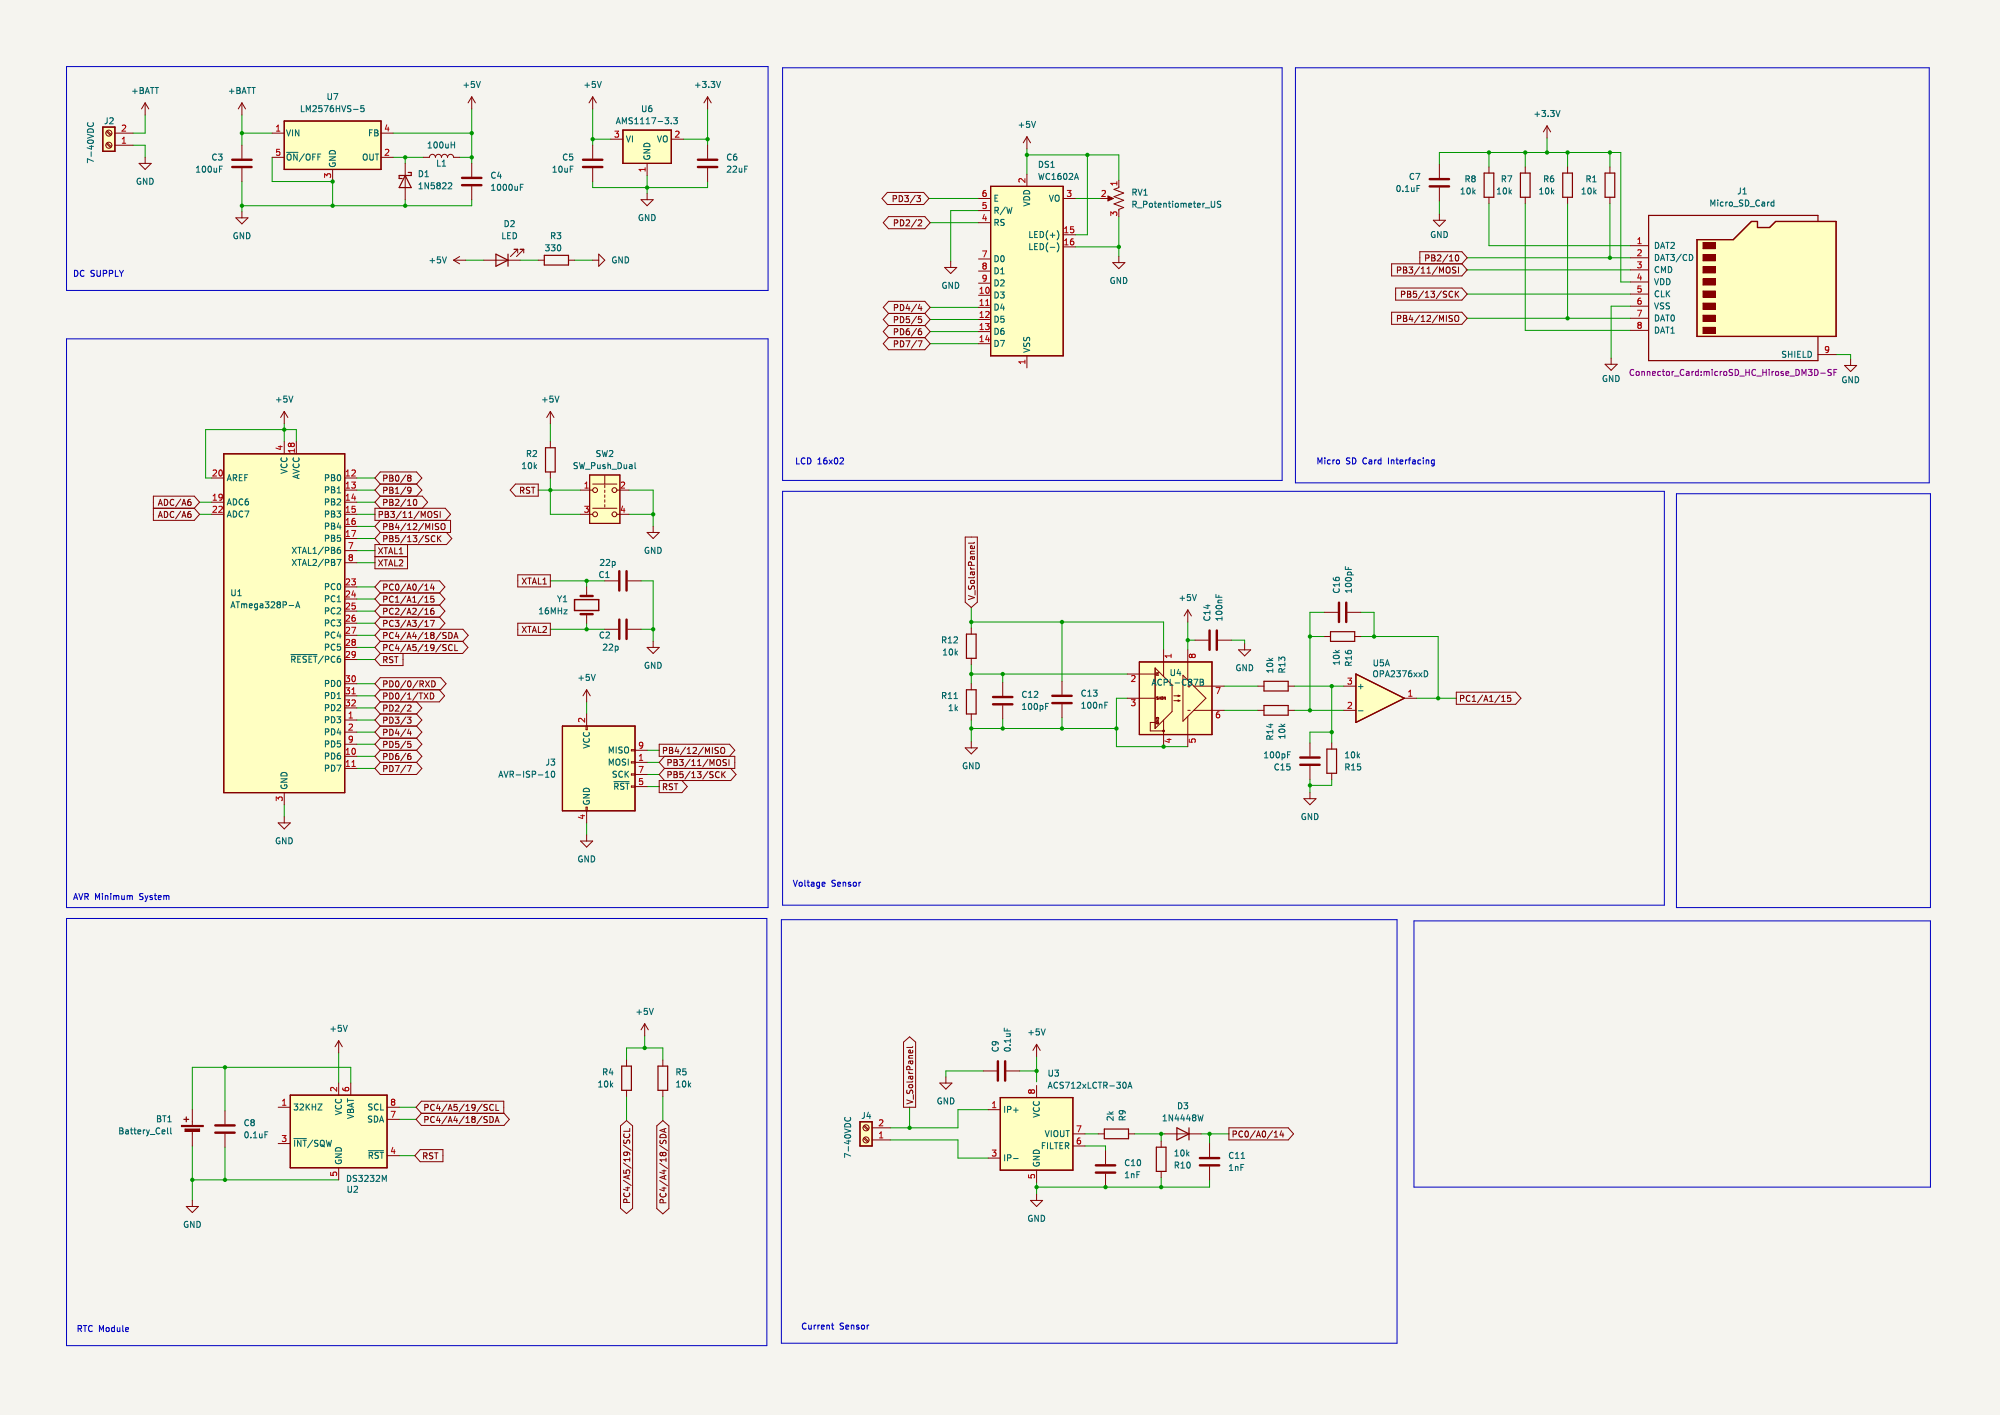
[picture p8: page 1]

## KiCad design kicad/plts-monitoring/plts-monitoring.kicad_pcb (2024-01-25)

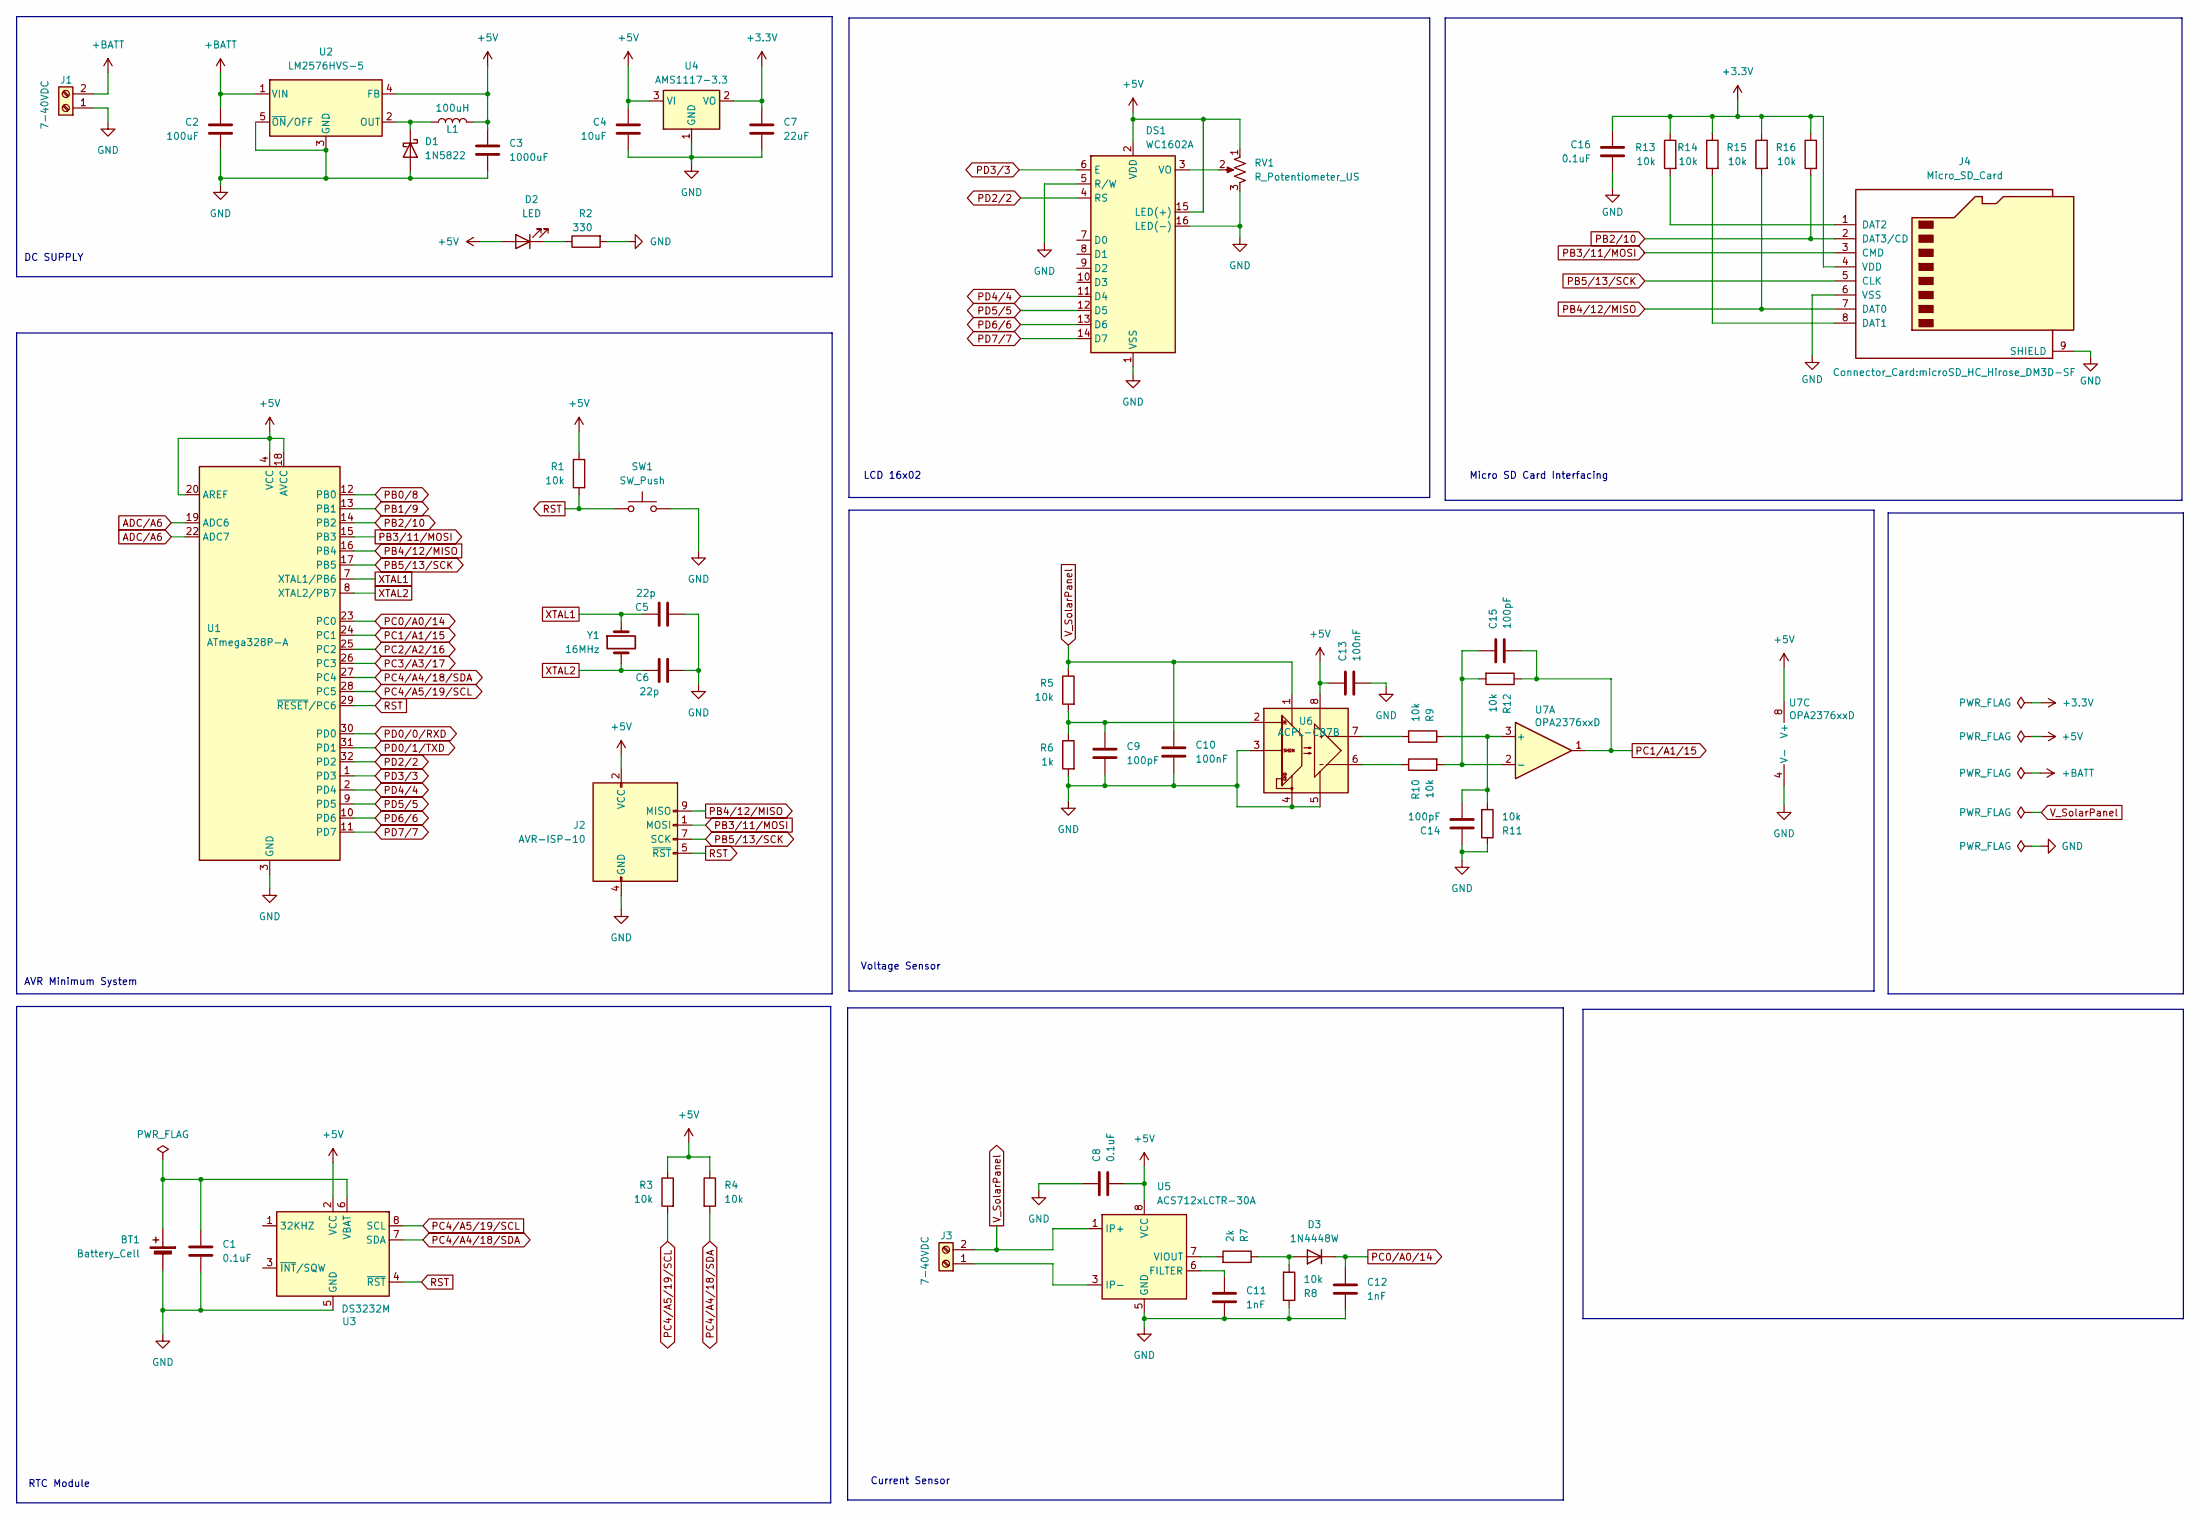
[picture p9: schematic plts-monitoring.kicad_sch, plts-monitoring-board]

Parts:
BT1: Battery_Cell; BatteryHolder_Keystone_3000_1x12mm
C1, C8: 0.1uF; CP_EIA-1608-10_AVX-L
C2: 100uF; CP_Elec_5x5.7
C3: 1000uF; CP_Elec_5x5.7
C4: 10uF; CP_EIA-2012-12_Kemet-R
C5, C6: 22p; C_0805_2012Metric
C7: 22uF; CP_EIA-2012-12_Kemet-R
C9, C14, C15: 100pF; CP_EIA-1608-10_AVX-L
C10, C13: 100nF; CP_EIA-1608-10_AVX-L
C11, C12: 1nF; CP_EIA-1608-10_AVX-L
C16: 0.1uF; CP_EIA-2012-12_Kemet-R
D1: 1N5822; D_DO-201AD_P15.24mm_Horizontal
D2: LED; LED_0805_2012Metric
D3: 1N4448W; D_SOD-123
DS1: WC1602A
J1, J3: 7-40VDC; TerminalBlock_Phoenix_MKDS-1,5-2-5.08_1x02_P5.08mm_Horizont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
J2: AVR-ISP-10; IDC-Header_2x05_P2.54mm_Vertical
J4: Micro_SD_Card; microSD_HC_Hirose_DM3D-SF
L1: 100uH; L_Bourns_SRP7028A_7.3x6.6mm
R1, R3, R4, R5, R8, R9, R10, R11, R12, R13, R14, R15, R16: 10k; R_0805_2012Metric
R2: 330; R_0805_2012Metric
R6: 1k; R_0805_2012Metric
R7: 2k; R_0805_2012Metric
RV1: R_Potentiometer_US; Potentiometer_Bourns_3224X_Vertical
SW1: SW_Push; SW_PUSH_6mm_H4.3mm
U1: ATmega328P-A; TQFP-32_7x7mm_P0.8mm
U2: LM2576HVS-5; TO-263-5_TabPin3
U3: DS3232M; SOIC-8_3.9x4.9mm_P1.27mm
U4: AMS1117-3.3; SOT-223-3_TabPin2
U5: ACS712xLCTR-30A; SOIC-8_3.9x4.9mm_P1.27mm
U6: ACPL-C87B; SSO-8_6.8x5.9mm_P1.27mm_Clearance8mm
U7: OPA2376xxD; TSSOP-8_3x3mm_P0.65mm
Y1: 16MHz; Crystal_SMD_2012-2Pin_2.0x1.2mm

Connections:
+3.3V: C7.1, C16.1, J4.4 (VDD), R13.1, R14.1, R15.1, R16.1, U4.2 (VO)
+5V: C3.1, C4.1, C8.2, C13.1, D2.2 (A), DS1.2 (VDD), DS1.15 (LED(+)), J2.2 (VCC), L1.2, R1.1, R3.1, R4.1, RV1.1, U1.4 (VCC), U1.6 (VCC), U1.18 (AVCC), U1.20 (AREF), U2.4 (FB), U3.2 (VCC), U4.3 (VI), U5.8 (VCC), U6.8 (VDD2), U7.8 (V+)
+BATT: C2.1, J1.2, U2.1 (VIN)
ADC/A6: U1.19 (ADC6), U1.22 (ADC7)
GND: BT1.2 (-), C1.2, C2.2, C3.2, C4.2, C5.2, C6.1, C7.2, C8.1, C9.2, C10.2, C11.2, C12.2, C13.2, C14.1, C16.2, D1.2 (A), DS1.1 (VSS), DS1.5 (R/W), DS1.16 (LED(-)), J1.1, J2.4 (GND), J2.6 (GND), J2.8 (GND), J2.10 (GND), J4.6 (VSS), J4.9 (SHIELD), R2.2, R6.2, R8.1, R11.1, RV1.3, SW1.2, U1.3 (GND), U1.5 (GND), U1.21 (GND), U2.3 (GND), U2.5 (~ON/OFF), U3.5 (GND), U4.1 (GND), U5.5 (GND), U6.3 (IN-), U6.4 (GND1), U6.5 (GND2), U7.4 (V-)
unnamed: BT1.1 (+), C1.1, U3.6 (VBAT)
unnamed: D1.1 (K), L1.1, U2.2 (OUT)
unnamed: D2.1 (K), R2.1
unnamed: D3.2 (A), R7.1, R8.2
unnamed: DS1.3 (VO), RV1.2
unnamed: J3.1, U5.3 (IP-), U5.4 (IP-)
unnamed: J4.8 (DAT1), R14.2
unnamed: J4.1 (DAT2), R13.2
unnamed: C11.1, U5.6 (FILTER)
unnamed: R7.2, U5.7 (VIOUT)
unnamed: C9.1, R5.2, R6.1, U6.2 (IN)
unnamed: R9.2, U6.7 (OUT+)
unnamed: R10.1, U6.6 (OUT-)
unnamed: C14.2, R9.1, R11.2, U7.3 (+)
unnamed: C15.1, R10.2, R12.2, U7.2 (-)
PB0/8: U1.12 (PB0)
PB1/9: U1.13 (PB1)
PB2/10: J4.2 (DAT3/CD), R16.2, U1.14 (PB2)
PB3/11/MOSI: J2.1 (MOSI), J4.3 (CMD), U1.15 (PB3)
PB4/12/MISO: J2.9 (MISO), J4.7 (DAT0), R15.2, U1.16 (PB4)
PB5/13/SCK: J2.7 (SCK), J4.5 (CLK), U1.17 (PB5)
PC0/A0/14: C12.1, D3.1 (K), U1.23 (PC0)
PC1/A1/15: C15.2, R12.1, U1.24 (PC1), U7.1
PC2/A2/16: U1.25 (PC2)
PC3/A3/17: U1.26 (PC3)
PC4/A4/18/SDA: R4.2, U1.27 (PC4), U3.7 (SDA)
PC4/A5/19/SCL: R3.2, U1.28 (PC5), U3.8 (SCL)
PD0/0/RXD: U1.30 (PD0)
PD0/1/TXD: U1.31 (PD1)
PD2/2: DS1.4 (RS), U1.32 (PD2)
PD3/3: DS1.6 (E), U1.1 (PD3)
PD4/4: DS1.11 (D4), U1.2 (PD4)
PD5/5: DS1.12 (D5), U1.9 (PD5)
PD6/6: DS1.13 (D6), U1.10 (PD6)
PD7/7: DS1.14 (D7), U1.11 (PD7)
RST: J2.5 (~RST), R1.2, SW1.1, U1.29 (~RESET/PC6), U3.4 (~RST)
V_SolarPanel: C10.1, J3.2, R5.1, U5.1 (IP+), U5.2 (IP+), U6.1 (VDD1)
XTAL1: C5.1, U1.7 (XTAL1/PB6), Y1.1
XTAL2: C6.2, U1.8 (XTAL2/PB7), Y1.2

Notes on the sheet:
LCD 16x02
RTC Module
DC SUPPLY
Current Sensor
Voltage Sensor
Micro SD Card Interfacing
AVR Minimum System

Board: 2 copper layers, 52 parts (0 on the bottom side), 38 nets, no tracks yet.

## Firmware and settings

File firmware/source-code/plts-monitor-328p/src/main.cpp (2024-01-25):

/*
 * PLTS MONITORING
 */
#include <SPI.h>
#include <SD.h>
#include <LiquidCrystal.h>
#include <DS3232RTC.h>
#include "MachineEnum/MachineEnum.h"
#include "MachineData/MachineData.h"
#include "Sensor/Sensor.h"

MachineData *mData;
LiquidCrystal *lcd;
Sensor *current;
Sensor *voltage;
DS3232RTC *rtc;

void sensorInit();
void rtcInit();
void sdInit();

void setup()
{
  // initialize the library by associating any needed LCD interface pin
  // with the arduino pin number it is connected to
  const uint8_t rs = 2, en = 3, d4 = 4, d5 = 5, d6 = 6, d7 = 7;
  lcd = new LiquidCrystal(rs, en, d4, d5, d6, d7);
  // set up the LCD's number of columns and rows:
  lcd->begin(16, 2);
  // Print a message to the LCD->
  lcd->print("Machine Setup...");
  //
  Serial.begin(9600);
  // Serial.println("Init");
  //
  mData = new MachineData;
  //
  sensorInit();
  //
  rtcInit();
  //
  sdInit();
  //

  lcd->setCursor(0, 1);
  lcd->print("      DONE      ");
  delay(1000);
  lcd->clear();
}

void loop()
{
  unsigned long prevMillisLog = 0;
  const long intervalLog = 1000; // ms
  char logText[32];              // yyyy-MM-dd;hh:mm:ss;AA.AA;VV.VV

  while (1)
  {
    unsigned long currentMillis = millis();

    if (currentMillis - prevMillisLog >= intervalLog)
    {
      prevMillisLog = currentMillis;

      // Sensor Reading
      current->setSensorValueAdc(analogRead(A0));
      current->routineTask();
      voltage->setSensorValueAdc(analogRead(A1));
      voltage->routineTask();
      //

      // Data Logging
      char dateStr[11];
      char timeStr[9];
      char ampsStr[6];
      char voltsStr[6];

      double amps = double(current->getSensorValue()) / 100.0;
      double volts = double(voltage->getSensorValue()) / 100.0;

      sprintf(dateStr, "%04d-%02d-%02d", year(), month(), day());
      sprintf(timeStr, "%02d:%02d:%02d", hour(), minute(), second());
      dtostrf(amps, 4, 2, ampsStr);
      dtostrf(volts, 4, 2, voltsStr);

      sprintf(logText, "%s;%s;%s;%s", dateStr, timeStr, ampsStr, voltsStr);

      // open the file. note that only one file can be open at a time,
      // so you have to close this one before opening another.
      File dataFile = SD.open("datalog.csv", FILE_WRITE);
      // if the file is available, write to it:
      if (dataFile)
      {
        dataFile.println(logText);
        dataFile.close();
        // print to the serial port too:
        Serial.println(logText);
      }
      // if the file isn't open, pop up an error:
      else
      {
        // Serial.println("error opening datalog.csv");
      }
      //

      // Display on LCD
      char row1Str[17], row2Str[17];
      timeStr[5] = '\0';
      sprintf(row1Str, "%s %s", dateStr, timeStr);
      sprintf(row2Str, "A:%s  V:%s", ampsStr, voltsStr);

      lcd->clear();
      lcd->home();
      lcd->print(row1Str);
      lcd->setCursor(0, 1);
      lcd->print(row2Str);
      //
    }
  }
}

/// @brief Sensor initialization (must init the MachineData instance first)
void sensorInit()
{
  if (mData == NULL)
  {
    // Serial.println("mData is not defined!");
    return;
  }
  current = new Sensor;
  voltage = new Sensor;

  // Current Sensor Init
  current->setSpSensorValue(CalPoint_1, mData->getSpCurrentSensor(CalPoint_1));
  current->setSpSensorValue(CalPoint_2, mData->getSpCurrentSensor(CalPoint_2));
  current->setSpSensorValue(CalPoint_3, mData->getSpCurrentSensor(CalPoint_3));
  current->setSpSensorValueAdc(CalPoint_1, mData->getSpCurrentSensorAdc(CalPoint_1));
  current->setSpSensorValueAdc(CalPoint_2, mData->getSpCurrentSensorAdc(CalPoint_2));
  current->setSpSensorValueAdc(CalPoint_3, mData->getSpCurrentSensorAdc(CalPoint_3));
  current->initScope();

  // Voltage Sensor Init
  voltage->setSpSensorValue(CalPoint_1, mData->getSpVoltageSensor(CalPoint_1));
  voltage->setSpSensorValue(CalPoint_2, mData->getSpVoltageSensor(CalPoint_2));
  voltage->setSpSensorValue(CalPoint_3, mData->getSpVoltageSensor(CalPoint_3));
  voltage->setSpSensorValueAdc(CalPoint_1, mData->getSpVoltageSensorAdc(CalPoint_1));
  voltage->setSpSensorValueAdc(CalPoint_2, mData->getSpVoltageSensorAdc(CalPoint_2));
  voltage->setSpSensorValueAdc(CalPoint_3, mData->getSpVoltageSensorAdc(CalPoint_3));
  voltage->initScope();
}

void rtcInit()
{
  rtc = new DS3232RTC;

  rtc->begin();
  setSyncProvider(rtc->get);
  if (timeStatus() == timeSet)
  {
    if (year() < 2024)
    {
      time_t t;
      tmElements_t tm;
      tm.Year = CalendarYrToTm(2024);
      tm.Month = 1;
      tm.Day = 25;
      tm.Hour = 23;
      tm.Minute = 59;
      tm.Second = 59;
      t = makeTime(tm);
      rtc->set(t);
      setTime(t);
    }
  }
}

void sdInit()
{
  const int chipSelect = 10;

  // Serial.print("Initializing SD card...");

  // see if the card is present and can be initialized:
  if (!SD.begin(chipSelect))
  {
    // Serial.println("Card failed, or not present");
    // don't do anything more:
    while (1)
      ;
  }
  // Serial.println("card initialized.");

  // One time execution only
  // open the file. note that only one file can be open at a time,
  // so you have to close this one before opening another.
  File dataFile = SD.open("datalog.csv", FILE_WRITE);
  // if the file is available, write to it:
  if (dataFile)
  {
    dataFile.println("Date;Time;Current (A);Voltage(V)");
    dataFile.close();
    // print to the serial port too:
    // Serial.println("Date;Time;Current (A);Voltage(V)");
  }
  // if the file isn't open, pop up an error:
  else
  {
    Serial.println("error opening datalog.csv");
  }
  //
}

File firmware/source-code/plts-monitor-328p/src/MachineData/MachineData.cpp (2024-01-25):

#include "MachineData.h"
#include <EEPROM.h>

MachineData::MachineData(void)
{
    // Serial.println("MachineData constructor!");
    // m_machineState = 0;

    readEeprom();
}

MachineData::~MachineData()
{
    // Serial.println("MachineData destructor!");
}

void MachineData::updateEeprom()
{
    m_data.checksum = calculateChecksum(m_data);
    EEPROM.put(0, m_data);
}

/// @brief return true if the data match checksum
bool MachineData::readEeprom()
{
    ee_data dataTemp;
    EEPROM.get(0, dataTemp);

    uint8_t checksum = dataTemp.checksum;
    if (checksum == calculateChecksum(dataTemp))
    {
        m_data = dataTemp;
        Serial.println("Data checksum is matched!");
        return true;
    }
    else
    {
        initEeprom();
        Serial.println("Data checksum doesn't match!");
        return false;
    }
}

void MachineData::initEeprom()
{
    m_data.spCurrentSensor[CalPoint_1] = 0;
    m_data.spCurrentSensor[CalPoint_2] = 1000; // 10.00 A
    m_data.spCurrentSensor[CalPoint_3] = 2000; // 20.00 A
    m_data.spCurrentSensorAdc[CalPoint_1] = 0; // 0~1023
    m_data.spCurrentSensorAdc[CalPoint_2] = 512;
    m_data.spCurrentSensorAdc[CalPoint_3] = 1023;
    m_data.spVoltageSensor[CalPoint_1] = 0;
    m_data.spVoltageSensor[CalPoint_2] = 1200; // 12.00 V
    m_data.spVoltageSensor[CalPoint_3] = 2400; // 24.00 V
    m_data.spVoltageSensorAdc[CalPoint_1] = 0; // 0~1023
    m_data.spVoltageSensorAdc[CalPoint_2] = 512;
    m_data.spVoltageSensorAdc[CalPoint_3] = 1023;
    updateEeprom();
}

uint8_t MachineData::calculateChecksum(const ee_data &data)
{
    const unsigned char *byteData = reinterpret_cast<const unsigned char *>(&data);
    uint8_t checksum = 0;

    for (size_t i = 0; i < sizeof(data) - sizeof(checksum); ++i)
    {
        checksum += byteData[i];
    }

    return checksum;
}

// uint8_t MachineData::getMachineState() const { return m_machineState; }

int MachineData::getSpCurrentSensor(uint8_t point)
{
    point = constrain(point, CalPoint_1, CalPoint_3);
    return m_data.spCurrentSensor[point];
}

int MachineData::getSpCurrentSensorAdc(uint8_t point)
{
    point = constrain(point, CalPoint_1, CalPoint_3);
    return m_data.spCurrentSensorAdc[point];
}

int MachineData::getSpVoltageSensor(uint8_t point)
{
    point = constrain(point, CalPoint_1, CalPoint_3);
    return m_data.spVoltageSensor[point];
}

int MachineData::getSpVoltageSensorAdc(uint8_t point)
{
    point = constrain(point, CalPoint_1, CalPoint_3);
    return m_data.spVoltageSensorAdc[point];
}

// void MachineData::setMachineData(uint8_t newValue)
// {
//     if (m_machineState == newValue)
//         return;
//     m_machineState = newValue;
// }

void MachineData::setSpCurrentSensor(uint8_t point, int newValue)
{
    point = constrain(point, CalPoint_1, CalPoint_3);
    if (m_data.spCurrentSensor[point] == newValue)
        return;
    m_data.spCurrentSensor[point] = newValue;
}

void MachineData::setSpCurrentSensorAdc(uint8_t point, int newValue)
{
    point = constrain(point, CalPoint_1, CalPoint_3);
    if (m_data.spCurrentSensorAdc[point] == newValue)
        return;
    m_data.spCurrentSensorAdc[point] = newValue;
}

void MachineData::setSpVoltageSensor(uint8_t point, int newValue)
{
    point = constrain(point, CalPoint_1, CalPoint_3);
    if (m_data.spVoltageSensor[point] == newValue)
        return;
    m_data.spVoltageSensor[point] = newValue;
}

void MachineData::setSpVoltageSensorAdc(uint8_t point, int newValue)
{
    point = constrain(point, CalPoint_1, CalPoint_3);
    if (m_data.spVoltageSensorAdc[point] == newValue)
        return;
    m_data.spVoltageSensorAdc[point] = newValue;
}

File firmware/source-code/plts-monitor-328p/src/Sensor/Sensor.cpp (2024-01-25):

#include "Sensor.h"

Sensor::Sensor(void)
{
    // Serial.println("Sensor constructor!");
    m_sensorValue = 0;
    m_sensorValueAdc = 0;
    // m_sensorValueAdcFiltered = 0;
    // m_sensorValueAdcTotal = 0;

    for (uint8_t i = 0; i < CalPoint_Total; i++)
    {
        m_spSensorValue[i] = 0;
        m_spSensorValueAdc[i] = 0;
    }
    for (uint8_t i = 0; i < CalPoint_Total - 1; i++)
    {
        m_m[i] = 0;
        m_b[i] = 0;
    }
}

Sensor::~Sensor()
{
    // Serial.println("Sensor destructor!");
}

void Sensor::routineTask()
{
    // _filterMovingAverageAdc();

    int sensorAdc = m_sensorValueAdc;
    double sensorValue = 0;

    if (sensorAdc < m_spSensorValueAdc[CalPoint_1])
    {
        sensorValue = 0;
    }
    else if (sensorAdc < m_spSensorValueAdc[CalPoint_2])
    {
        if (m_m[CalPoint_2 - 1] != 0)
            sensorValue = ((double)sensorAdc - m_b[CalPoint_2 - 1]) / m_m[CalPoint_2 - 1];
    }
    else
    {
        if (m_m[CalPoint_3 - 1] != 0)
            sensorValue = ((double)sensorAdc - m_b[CalPoint_3 - 1]) / m_m[CalPoint_3 - 1];
    }
    m_sensorValue = round(sensorValue);
    // Serial.print("sensorValue ");
    // Serial.print(sensorValue);
    // Serial.print(" m_sensorValue ");
    // Serial.println(m_sensorValue);
}

void Sensor::initScope()
{
    double temp = (m_spSensorValue[CalPoint_2] - m_spSensorValue[CalPoint_1]);
    if (temp != 0)
    {
        m_m[CalPoint_1] = (static_cast<double>(m_spSensorValueAdc[CalPoint_2] - m_spSensorValueAdc[CalPoint_1])) / temp;
        m_b[CalPoint_1] = (static_cast<double>(m_spSensorValueAdc[CalPoint_1])) - (m_m[CalPoint_1] * m_spSensorValue[CalPoint_1]);
    }

    temp = (m_spSensorValue[CalPoint_3] - m_spSensorValue[CalPoint_2]);
    if (temp != 0)
    {
        m_m[CalPoint_2] = (static_cast<double>(m_spSensorValueAdc[CalPoint_3] - m_spSensorValueAdc[CalPoint_2])) / temp;
        m_b[CalPoint_2] = (static_cast<double>(m_spSensorValueAdc[CalPoint_2])) - (m_m[CalPoint_2] * m_spSensorValue[CalPoint_2]);
    }
}

int Sensor::getSpSensorValue(uint8_t point) const
{
    point = constrain(point, CalPoint_1, CalPoint_3);
    return m_spSensorValue[point];
}

int Sensor::getSpSensorValueAdc(uint8_t point) const
{
    point = constrain(point, CalPoint_1, CalPoint_3);
    return m_spSensorValueAdc[point];
}

int Sensor::getSensorValue() const
{
    return m_sensorValue;
}

int Sensor::getSensorValueAdc() const
{
    return m_sensorValueAdc;
}

// bool Sensor::getMovingAverageEnabled() const
// {
//     return m_movingAverageEnabled;
// }

void Sensor::setSpSensorValue(uint8_t point, int newValue)
{
    point = constrain(point, CalPoint_1, CalPoint_3);
    if (m_spSensorValue[point] == newValue)
        return;
    m_spSensorValue[point] = newValue;
}

void Sensor::setSpSensorValueAdc(uint8_t point, int newValue)
{
    point = constrain(point, CalPoint_1, CalPoint_3);
    if (m_spSensorValueAdc[point] == newValue)
        return;
    m_spSensorValueAdc[point] = newValue;
}

void Sensor::setSensorValue(int newValue)
{
    if (m_sensorValue == newValue)
        return;
    m_sensorValue = newValue;
}

void Sensor::setSensorValueAdc(int newValue)
{
    if (m_sensorValueAdc == newValue)
        return;
    m_sensorValueAdc = newValue;
}

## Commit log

2024-01-21 Update all materials for hardware design
2024-01-24 New class for sensor and fixed wrong constraint limit of in MachineData
    [MachineData.cpp, Sensor.cpp, main.cpp]
2024-01-24 Default max current value 20A, add kicad project
    [plts-monitoring.kicad_pcb, plts-monitoring.kicad_sch]
2024-01-24 Add Micro SD Card footprint
    [plts-monitoring.kicad_sch]
2024-01-25 Add moving average function for sensor ADC reading
2024-01-25 Fixed Data Time not showing on the LCD
    [main.cpp]
2024-01-25 Update KiCad schematic
    [plts-monitoring.kicad_sch]
2024-01-25 Update schematic to pass ERC and some footprints
    [plts-monitoring.kicad_pcb, plts-monitoring.kicad_sch]
